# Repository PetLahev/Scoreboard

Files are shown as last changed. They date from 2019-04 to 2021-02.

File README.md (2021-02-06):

# Scoreboard 
Scoreboard created with [LED strips](https://www.amazon.com/FAVOLCANO-Waterproof-Feet%EF%BC%885M%EF%BC%89-Flexible-Lighting/dp/B012FFZP70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), ~~[Arduino Nano](https://www.amazon.com/Arduino-A000005-ARDUINO-Nano/dp/B0097AU5OU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)~~ [Arduino Uno](https://www.amazon.com/Arduino-A000066-ARDUINO-UNO-R3/dp/B008GRTSV6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) and some manual work. Handy for volleyball, table tennis, badminton, football etc.

### Why Arduino UNO
I wanted to use Nano and I designed the motherboard for using Nano but unfortunately it appeared to have one, not that serious problem for others,  but [blocker for me](https://stackoverflow.com/questions/55680065/arduino-nano-hm-10-module-not-receiving-data-on-mobile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). I was basically not able to send messages back to the HM-10 bluetooth module which is the 'main feature' of this whole scoreboard.
Thus after I built everything and was in the testing phase I found out that bluetooth communication is not working as I like. So instead of using the motherboard PCB I simply bought [UNO holder](https://store.arduino.cc/holder-type-uno) and a [terminal for UNO](https://www.amazon.com/Aideepen-Assembled-Prototype-Expansion-Bareboard/dp/B01JFQQXRS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) and made the scoreboard with it. Not that big problem as I have enough space in the box but hey ...

Scoreboard no LED strips Scoreboard powered Motherboard PCB Scorecontroller PCB Back side All PCBs

* 50 x 70 cm (19.7 x 27.55 inch) height x width
* Each segment 10 cm (3.93 inch) length so 20 cm (7.9 inch) one number! (*for points*)
* Each LED strip controlled by its own transistor
* Controlled by bluetooth module ([HM-10 Bluetooth 4.0 BLE](https://www.amazon.com/DSD-TECH-Bluetooth-iBeacon-Arduino/dp/B06WGZB2N4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))
    * Also possible to control via 433MHz module or an infra red (IR) controller
* You can use pre-defined setup for a game
* You can setup your own game
* Supports tiebreaks, sets and displaying players on service
* Score can be updated by buttons (either wired or wireless)
* As of April 2019 a free Androind application is used for controlling the scoreboard - [Serial Bluetooth Terminal](https://play.google.com/store/apps/details?id=de.kai_morich.serial_bluetooth_terminal&hl=en_US) v1.17
	* Update Feb 2021 - It was proven that the most convinient way how to control the scoreboard is an IR controller (people tend to prefer this way over others)
* Eagle schematic and boards included
* The scoreboard case designed on thinkercad.com
    * [The box](https://www.tinkercad.com/things/gNmK0jQ22qv)
    * [The display board](https://www.tinkercad.com/things/9Don7XhJEvx) - just for measuring purpose

## Setting the Serial Bluetooth Terminal
Just one device can be connected to the module at time!
Make sure you pair the bluetooth module with your smart phone, add it under the `Devices` tab and then go to the `Settings - Send` and set the `Newline` option to **none**. On the main menu tap on the connect symbol. You should get a text saying "Connected to unnamed". (*Make sure you bluetooth module is powered and the indication LED is blinking*)

## Settings
By default, the scoreboard is set as a clock (sets segment are used for seconds). There is no specific setting for turning the clock
off as this is always done by providing any setting. If you need to go back to the 'clock' mode, just turn the power off and then on.
You can setup your own game either in code - [globals.cpp](/Arduino/Scoreboard/src/globals.cpp) - or at runtime when sending the SETTING character via the Serial Bluetooth Terminal. The SETTING character is = `!` (*exclamation mark*). This behaves as a toggle switch so when send first time `!` the scoreboard will switch to 'setting mode' and will accept certain settings, when sending second time `!` it will end the 'setting mode' and will be ready for a game!

You can setup
* Number of sets (up to 9)
* Sets support - enabled/disabled
    * Number of points per a set (up to 99)
* Points difference to win a set
* Tiebreak support - enabled/disabled
    * Points in tiebreak
    * Points difference to win a tiebreak set
    * The tiebreak set
        * Set a number that represents the set in the match considered as tiebreak set. *For example, in tennis you would set number `7` here*
* Display player on service (*pre-set 4 players*) - enabled/disabled

### Application settings
The code now (*April 2019*) understands certain `key=value` pairs. Listed below but always check [settingController](/Arduino/Scoreboard/src/settingController.h) header file for the latest settings
* Enable displaying sets = `b`
* Sets per match = `s`
* Points per set = `e`
* Points difference to win a set = `d`
* Support tiebreak = `t`
* Set the tiebreak set = `q`
* Points in tiebreak = `f`
* Points difference to win a tiebreak = `w`
* Enable displaying a player on service = `r`
* Swap score = `$`
* Set player on service = `p` and then number 1 - 4
* Reset the whole game = `@`
* Turn sets segments to minute timer = `u`
    * Will automatically enable displaying sets

Examples of key-value setting

    b=true
    WIll enable sets (the LEDs will be powered)

    s=2
    A team/player needs to win 2 sets to win the match

    e=11
    A team/player needs to win 11 points to win a set
    (The points difference setting will be considered here)

    d=2
    A set will be considered as finished when the score between the teams/players
    1, reach the minimum points to win a set (e.g. 11)
    AND
    2, the difference is equal to 2
    examples: 11:9 or 13:11 or 12:10 or 21:19 etc.

    t=true
    Tiebreak is enabled

    q=2
    The tiebreak set is the second set to win. In other words this will be the third set
    For the above example the tiebreak settings will be considered when sets are 1:1

    f=9
    A team/player needs to win 9 points to win the tiebreak set

    w=2
    The tiebreak will be considered as finished when the score between the teams/players
    1, reach the minimum points to win the tiebreak set (e.g. 9)
    AND
    2, the difference is equal to 2
    examples: 9:7 or 10:8 or 11:9 etc.

    r=true
    Will enable displaying player on service (The LEDs will be powered)
    Note: There are always 4 players pre-set, not configurable as of April 2019)

    u=true
    Will turn the sets segments to display minute timer. So it will count from 0 to 9999 minutes

### Example of game settings
#### A free match (like football)
    b=false   ' disable sets
    s=0       ' no sets per match  
    e=99      ' set maximum of points
    t=false   ' tiebreak disabled
    r=false   ' disable displaying player on service

#### A beach volleyball match
    b=true    ' enable sets
    s=2       ' a team needs to win 2 sets to win a match
    e=21      ' a team needs to win 21 points to win a set
    d=2       ' the points difference between the two teams must be 2 to win a set
    t=reuw    ' tiebreak enabled
    q=2       ' the tiebreak set is the second one to win. So the sets score is 1:1
    f=15      ' a team needs to win 15 points to win the tiebreak set
    w=2       ' the points difference between the two teams must be 2 to win the tiebreak set
    r=true    ' enable displaying a player who serves

## How to use
Once your game is set and you leave the settings mode (*by sending `!` flag*) your match can start. Based on the type of your match the scoreboard will control all the aspect of the match you will just increase or decrease number of points for the **Home** or **Away** team

Send  
`h` - to give a point to **Home** team  
`a` - to give a point to **Away** team

If you make a mistake (*we all do*) you can take a point back.  
Send  
`v` - to decrease points of **Home** team  
`m` - to decrease score of **Away** team

**Please note:** Taking point back may have an affect on number of sets played, match finished, player on service etc. The code as of April 2019 cares just about simple cases and supports returning all back just for *one* point so if you made a mistake and give a point in the middle of set to a wrong team, taking the point back will work but if you made the same mistake when the team you gave won a set/match then taking the point back will NOT have any affect. It's better to start a new match by resetting the match and setting the correct score by sending few `h` or `a`.

## How to build
OK if you get here you actually may want to build your own scoreboard and I do understand that, it's much more fun!

If you just want to take the code and change it be aware that I didn't use the official Arduino IDE as I didn't find it as good as it should be. This project is made by [Visual Studio Code](https://code.visualstudio.com/) and [Platform IO](https://platformio.org/) extension both free. Once installed you should be able to build the project as it has all the settings done so you will get the right versions of used libraries and everything else. Please check [platformio.ini](/Arduino/platformio.ini) file to see if I added your Arduino board to the environment configuration. As of April 2019 I have this configuration

    [platformio]
    env_default = uno

    [env:nanoatmega328]
    platform = atmelavr
    board = nanoatmega328
    framework = arduino

    [env:uno]
    platform = atmelavr
    framework = arduino
    board = uno

The `env_default = uno` specifies for which board Platform IO builds the code, in this case is Arduino Uno. Make sure you have the right one here otherwise the code won't work.  
Let me also make you aware that I'm not C++ guy and I found it pretty hard to learn so the code is probably all messy but working.

If you also want to build the scoreboard case check the [Tinkercad page](https://www.tinkercad.com/things/gNmK0jQ22qv). I tried to make it in 1:5 scale but again it was my first experience with 3D software. The [shield](https://www.tinkercad.com/things/9Don7XhJEvx) is there only for measurement purpose. I just wanted to see to what size all the LED strips will fit and how it will look like. Based on the size I designed the [case](https://www.tinkercad.com/things/gNmK0jQ22qv).  
In terms of material use whatever will fit you. My original plan was using plastic because I didn't want to make it heavy but still not too fragile. For the first version I ended up with a 5mm wood board you can buy in hobby markets asked a joiner to cut the board into pieces and let him actually figure out how to put it all together, it cost me just ~$10 then you just need to a drill and couple screws and put it all together

To be continued

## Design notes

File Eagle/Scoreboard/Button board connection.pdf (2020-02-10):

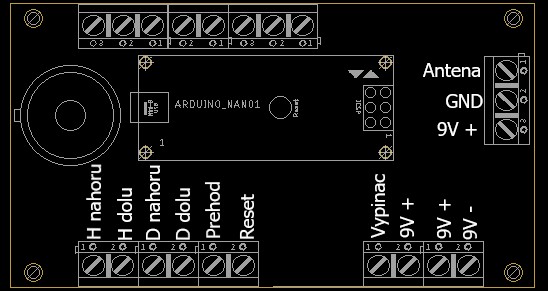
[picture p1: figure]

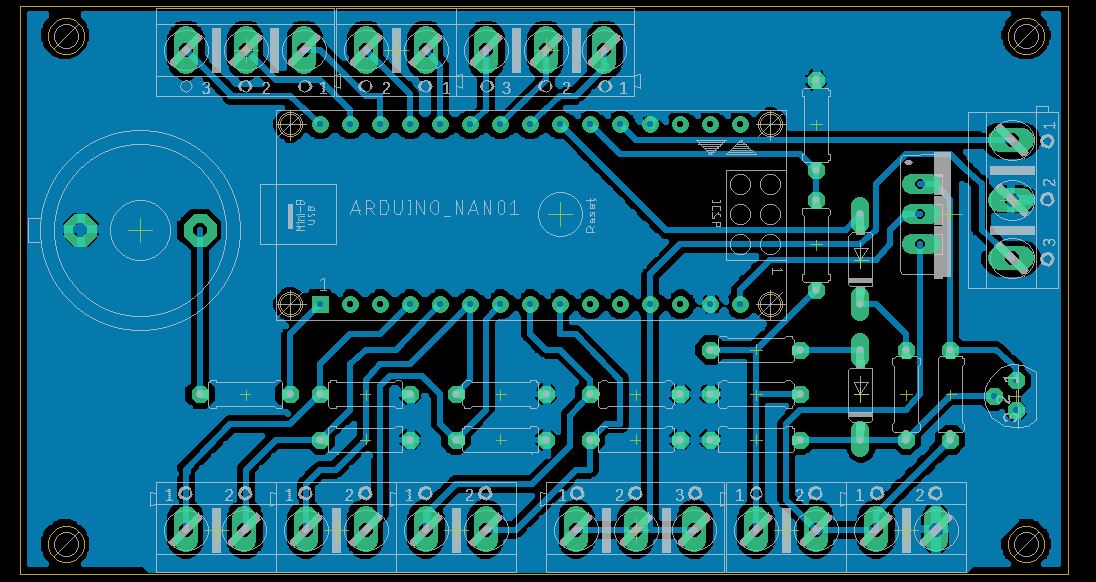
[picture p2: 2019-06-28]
images/WirelessController.png

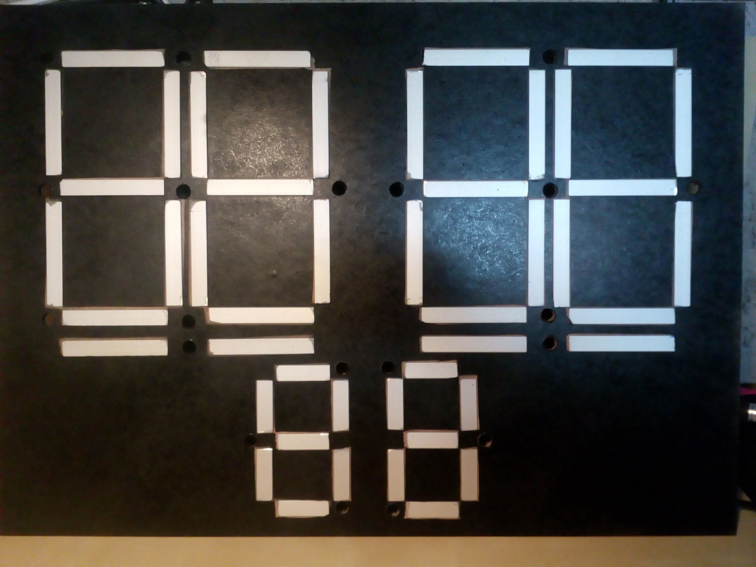
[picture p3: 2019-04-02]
images/Scoreboard no LED strips.png

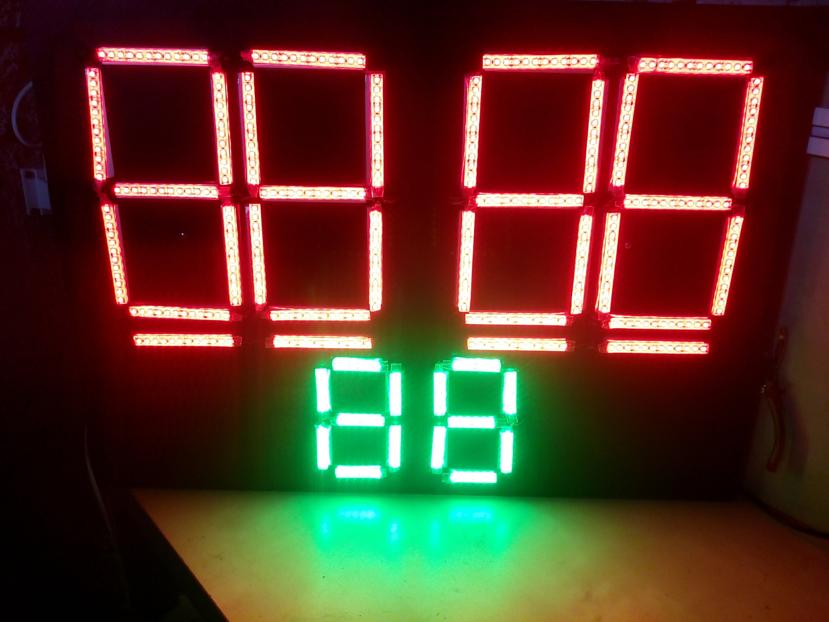
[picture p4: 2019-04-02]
images/Scoreboard powered.png

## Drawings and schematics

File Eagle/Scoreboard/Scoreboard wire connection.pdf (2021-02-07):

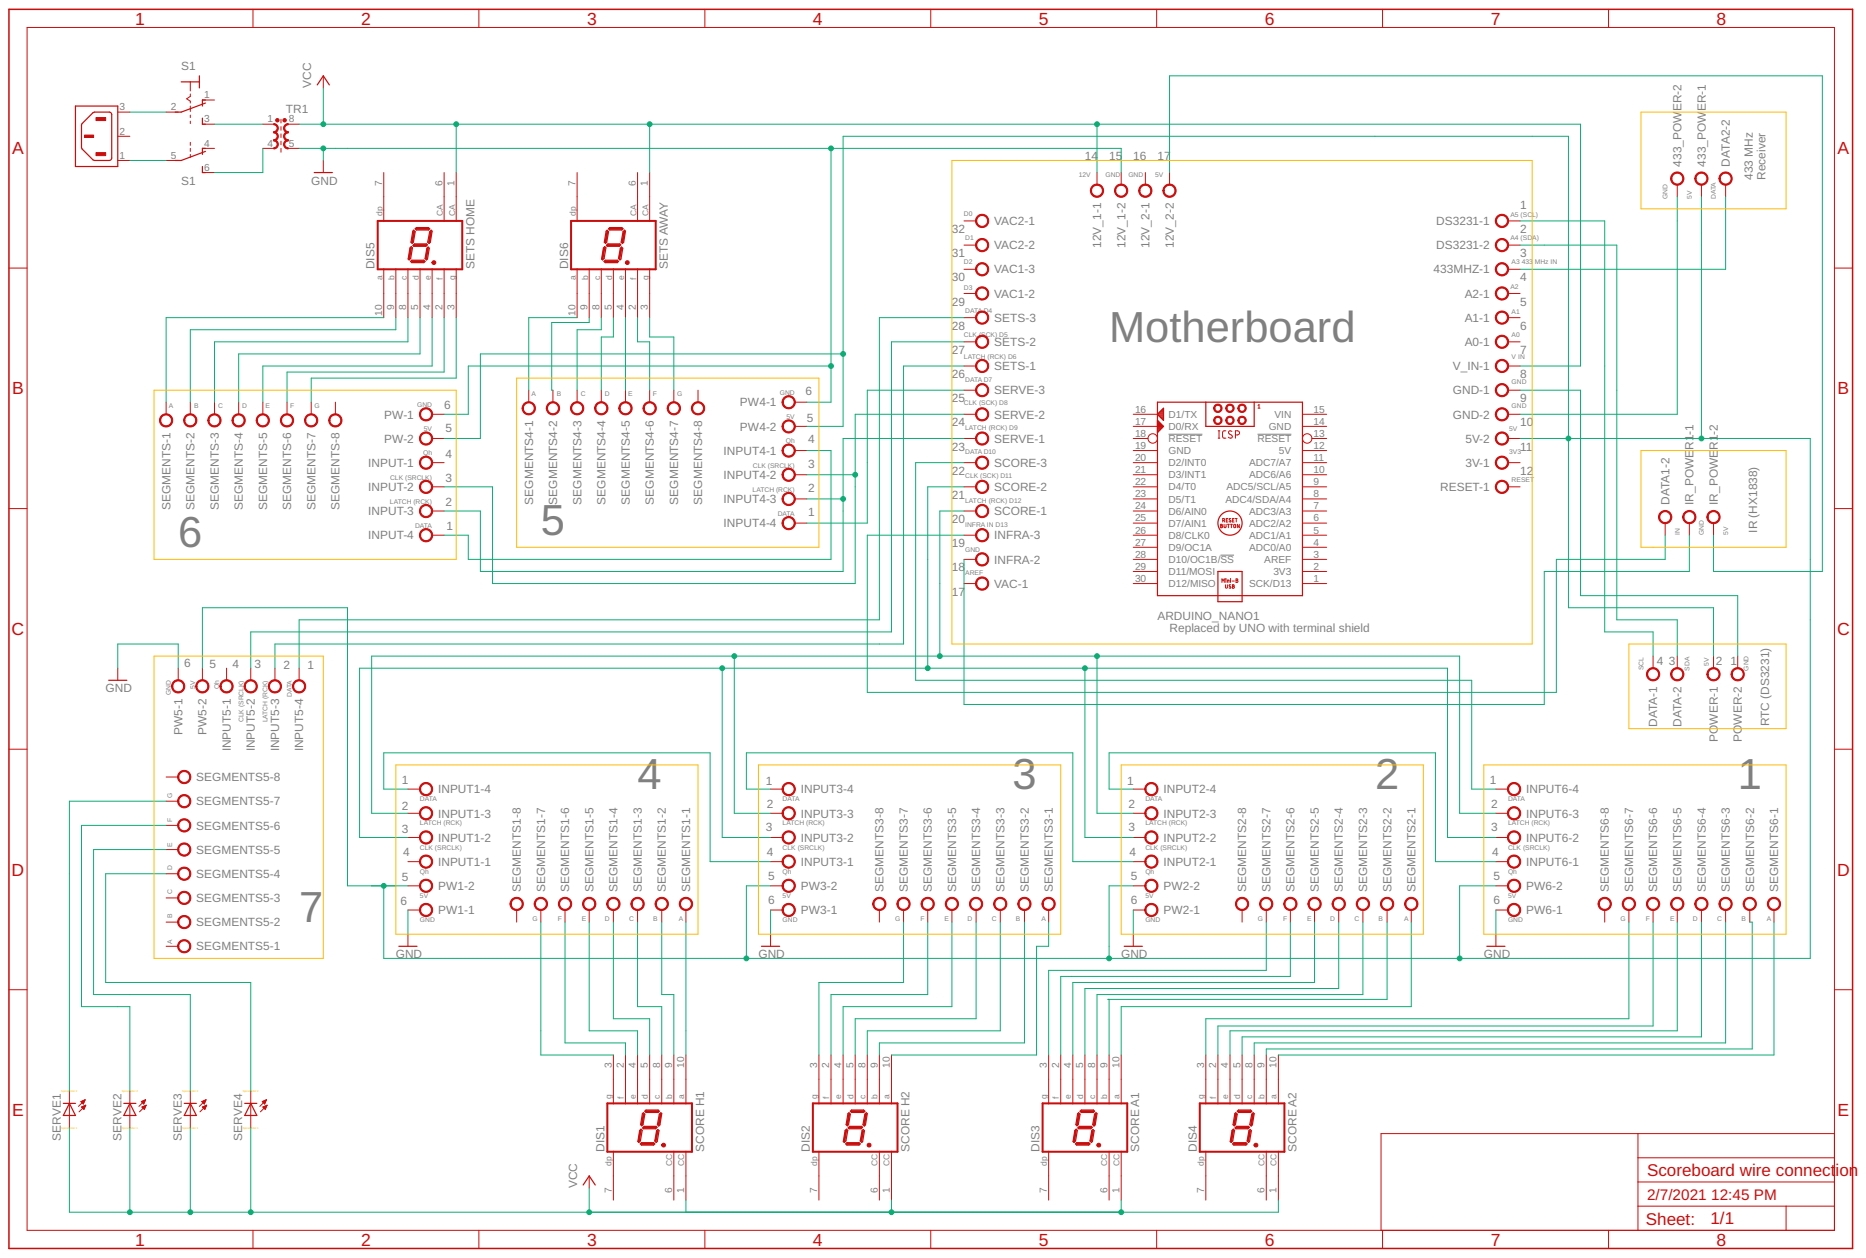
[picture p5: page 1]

LATCH (RCK) D9 CLK (SCK) D8 DATA D7
SERVE-3

LATCH (RCK) D12 CLK (SCK) D11 DATA D10
SCORE-3

LATCH (RCK) CLK (SRCLK)
INPUT4-2

INPUT-2

ARDUINO_NANO1
Replaced by UNO with terminal shield

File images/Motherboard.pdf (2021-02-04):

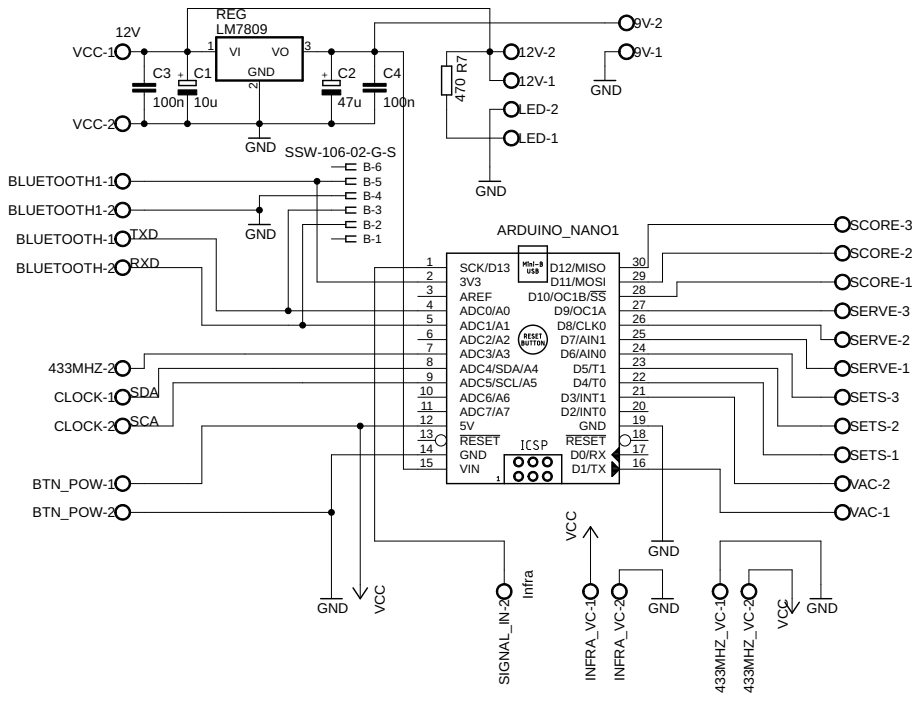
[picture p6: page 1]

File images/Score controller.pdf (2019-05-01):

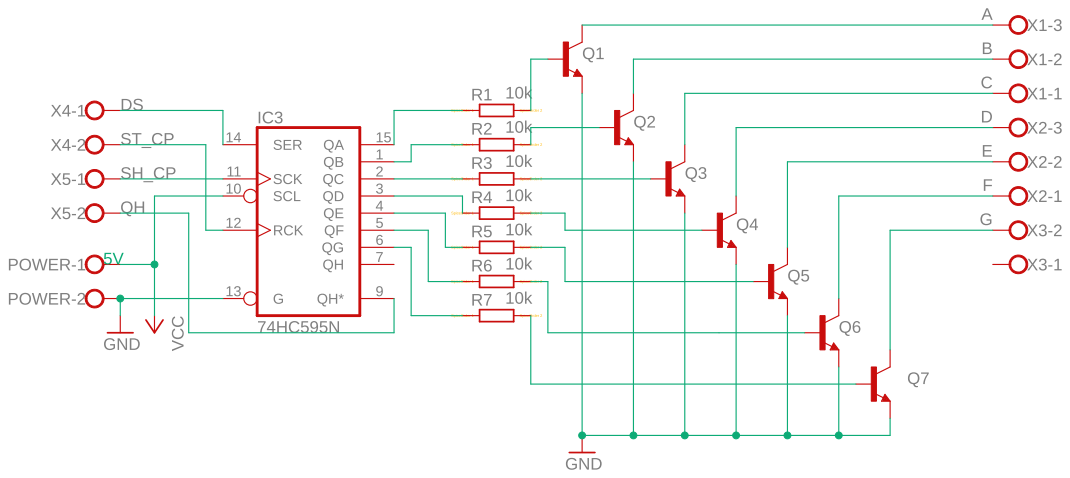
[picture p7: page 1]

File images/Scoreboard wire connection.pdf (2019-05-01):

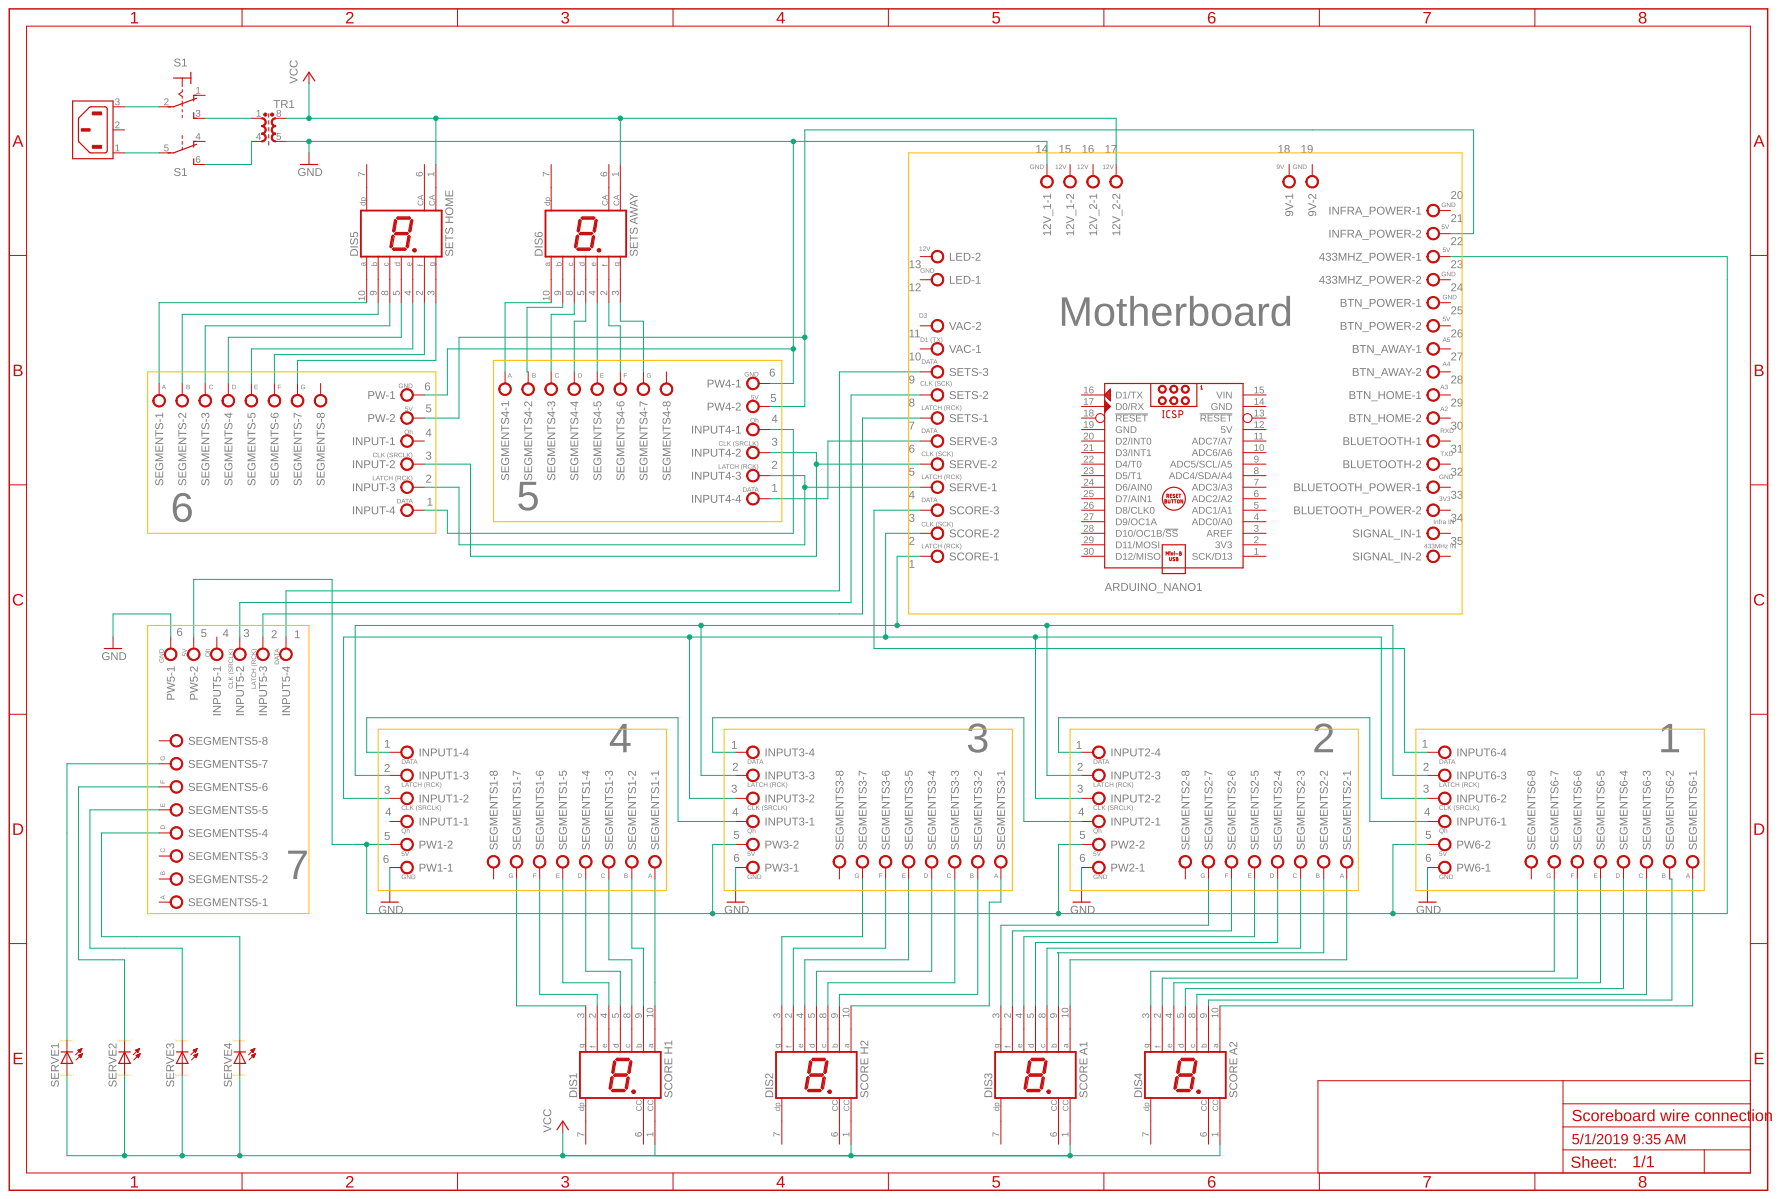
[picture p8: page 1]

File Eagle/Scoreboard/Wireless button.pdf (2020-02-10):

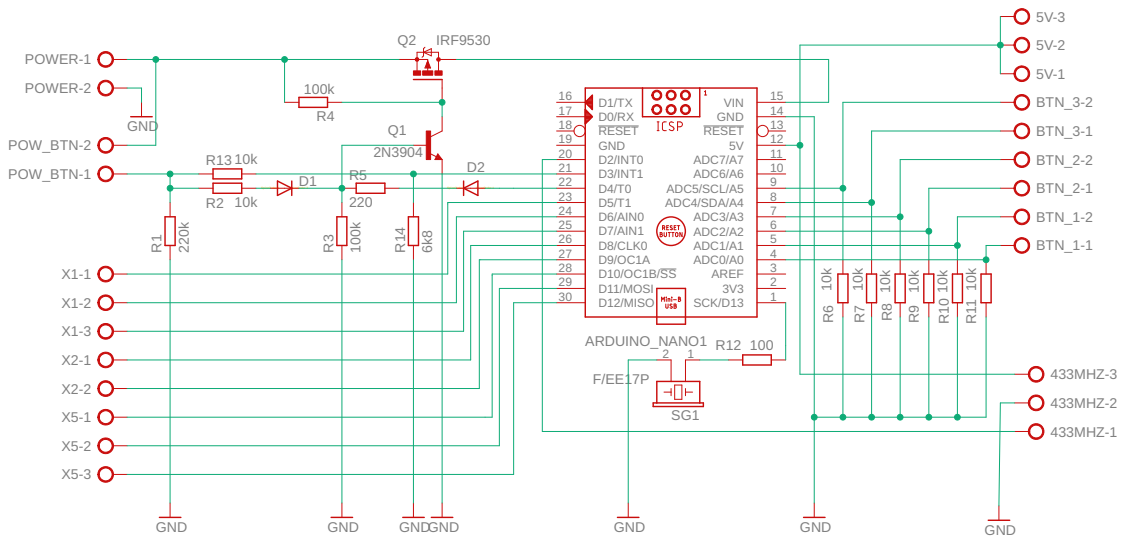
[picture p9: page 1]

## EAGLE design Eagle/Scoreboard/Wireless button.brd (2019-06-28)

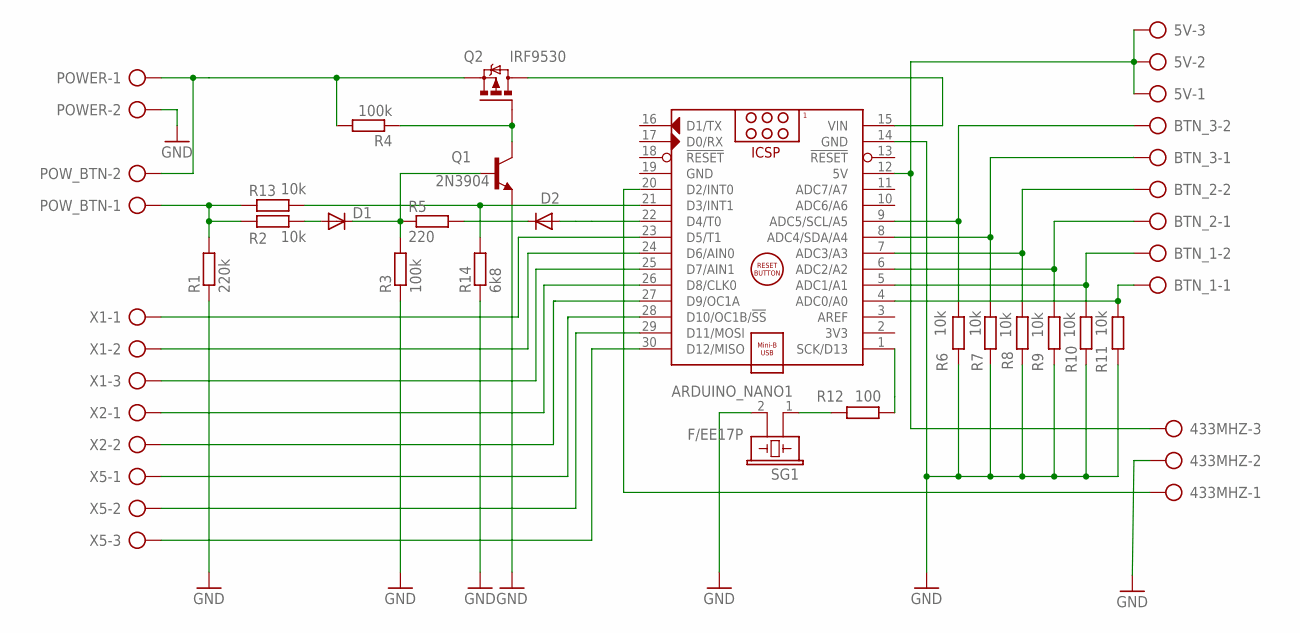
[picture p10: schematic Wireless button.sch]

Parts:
5V, 433MHZ: AK500/3
ARDUINO_NANO1: ARDUINO_NANO
BTN_1, BTN_2, BTN_3: AK500/2
D1, D2: 1N4148DO35-7; DO35-7
POWER: AK500/2
POW_BTN: AK500/2
Q1: 2N3904; TO92
Q2: IRF9530; TO220BV
R1: 220k; 0207/7
R2, R6, R7, R8, R9, R10, R11, R13: 10k; 0207/7
R3, R4: 100k; 0207/7
R5: 220; 0207/7
R12: 100; 0207/7
R14: 6k8; 0207/7
SG1: F/EE17P
X1, X5: AK500/3
X2: AK500/2

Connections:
5V: 5V.1, 5V.2, 5V.3, 433MHZ.3, ARDUINO_NANO1.12 (5V)
AWAY_DOWN: ARDUINO_NANO1.5 (ADC1/A1), BTN_1.2, R10.2
AWAY_UP: ARDUINO_NANO1.4 (ADC0/A0), BTN_1.1, R11.2
BUZZ: ARDUINO_NANO1.1 (SCK/D13), R12.2
GND: 433MHZ.2, ARDUINO_NANO1.14 (GND), ARDUINO_NANO1.19 (GND), POWER.2, Q1.3 (E), R1.1, R3.1, R6.1, R7.1, R8.1, R9.1, R10.1, R11.1, R14.1, SG1.2
HOME_DOWN: ARDUINO_NANO1.7 (ADC3/A3), BTN_2.2, R8.2
HOME_UP: ARDUINO_NANO1.6 (ADC2/A2), BTN_2.1, R9.2
unnamed: ARDUINO_NANO1.22 (D4/T0), D2.A
unnamed: Q1.1 (C), Q2.G, R4.1
unnamed: ARDUINO_NANO1.23 (D5/T1), X1.1
unnamed: D1.A, R2.2
unnamed: D1.C, Q1.2 (B), R3.2, R5.1
unnamed: D2.C, R5.2
unnamed: ARDUINO_NANO1.24 (D6/AIN0), X1.2
unnamed: ARDUINO_NANO1.25 (D7/AIN1), X1.3
unnamed: R12.1, SG1.1
unnamed: 433MHZ.1, ARDUINO_NANO1.20 (D2/INT0)
unnamed: ARDUINO_NANO1.26 (D8/CLK0), X2.1
unnamed: ARDUINO_NANO1.27 (D9/OC1A), X2.2
unnamed: ARDUINO_NANO1.28 (D10/OC1B/!SS), X5.1
unnamed: ARDUINO_NANO1.29 (D11/MOSI), X5.2
unnamed: ARDUINO_NANO1.30 (D12/MISO), X5.3
unnamed: ARDUINO_NANO1.21 (D3/INT1), R13.2, R14.2
OFF: POW_BTN.1, R1.2, R2.1, R13.1
POWER: POWER.1, POW_BTN.2, Q2.S, R4.2
RESET: ARDUINO_NANO1.9 (ADC5/SCL/A5), BTN_3.2, R6.2
SWAP: ARDUINO_NANO1.8 (ADC4/SDA/A4), BTN_3.1, R7.2
VCC: ARDUINO_NANO1.15 (VIN), Q2.D

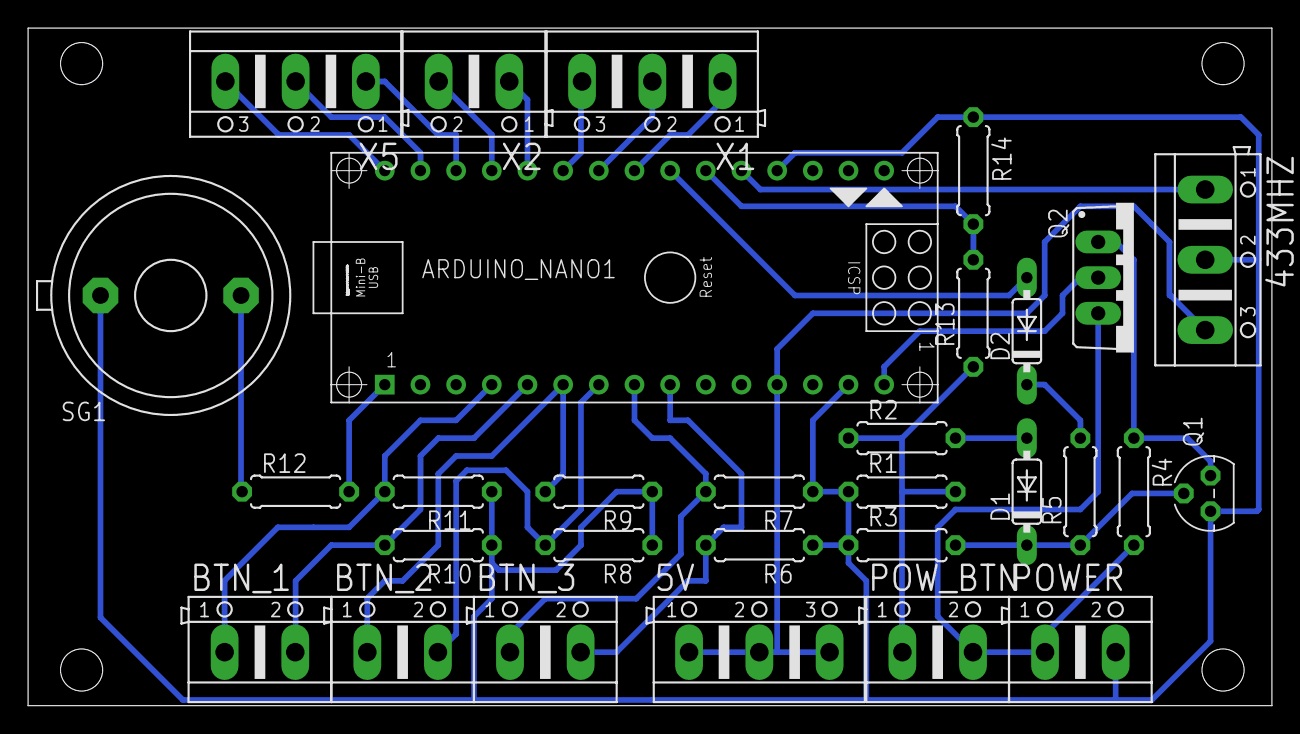
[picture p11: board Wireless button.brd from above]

Board: 2 copper layers, 88.6 x 48.2 mm, 30 parts (0 on the bottom side), 28 nets.

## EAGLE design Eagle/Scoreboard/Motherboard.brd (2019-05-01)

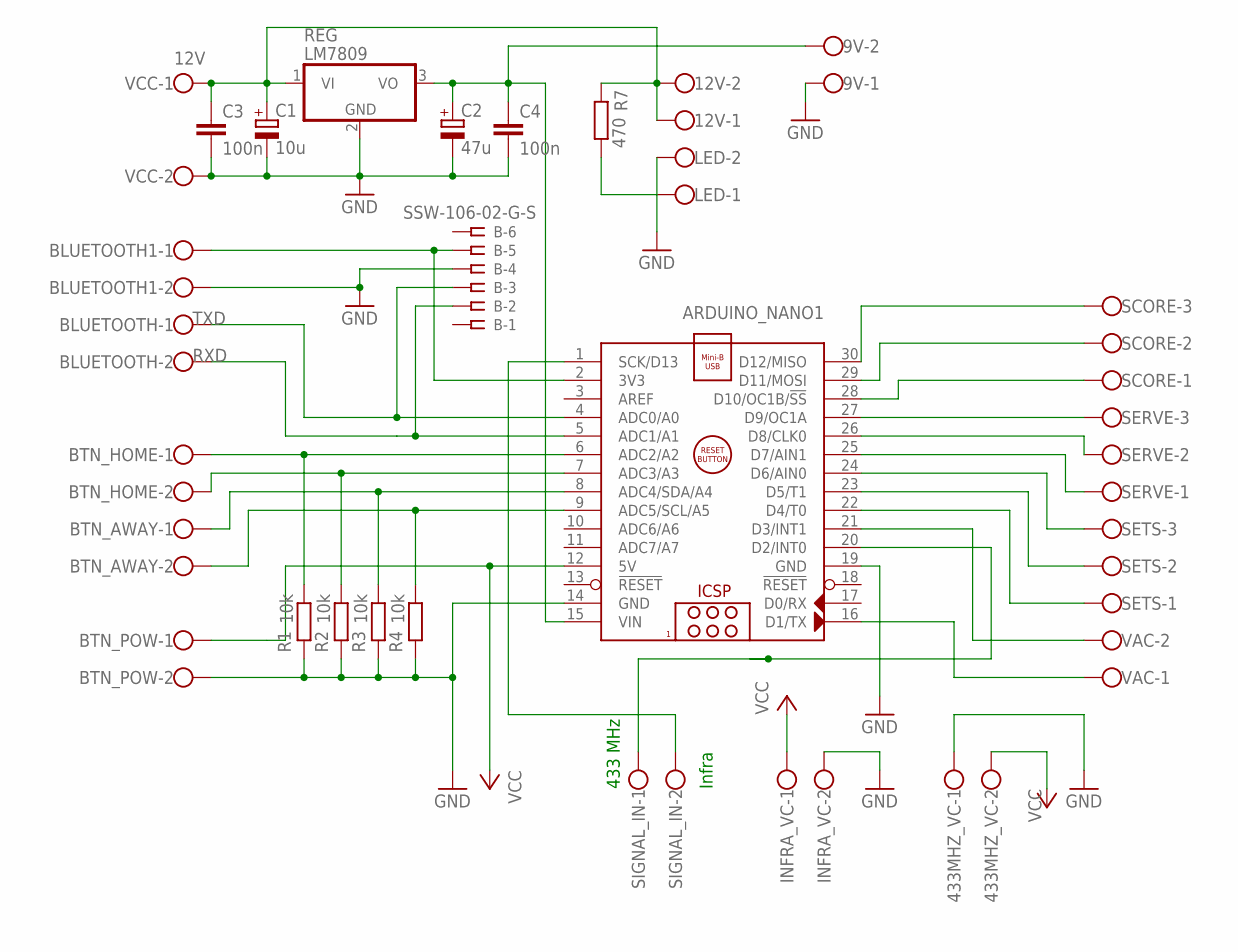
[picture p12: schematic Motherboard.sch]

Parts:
9V, 12V, 433MHZ_VC: W237-102
ARDUINO_NANO1: ARDUINO_NANO
B: SSW-106-02-G-S
BLUETOOTH, BLUETOOTH1: W237-102
BTN_AWAY: W237-102
BTN_HOME: W237-102
BTN_POW: W237-102
C1: 10u; E2-4
C2: 47u; E2-4
C3, C4: 100n; C5B2.5
INFRA_VC: W237-102
LED: W237-102
R1, R2, R3, R4: 10k; 0204/7
R7: 470; 0204/7
REG: LM7809; TO220H
SCORE: W237-103
SERVE: W237-103
SETS: W237-103
SIGNAL_IN: W237-102
VAC: W237-102
VCC: W237-102

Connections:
3V3: ARDUINO_NANO1.2 (3V3), B.5, BLUETOOTH1.1
12V: 12V.1, 12V.2, C1.+, C3.1, R7.2, REG.1 (VI), VCC.1
433MHZ: ARDUINO_NANO1.20 (D2/INT0), SIGNAL_IN.1
A2: ARDUINO_NANO1.6 (ADC2/A2), BTN_HOME.1, R1.1
A3: ARDUINO_NANO1.7 (ADC3/A3), BTN_HOME.2, R2.1
A4: ARDUINO_NANO1.8 (ADC4/SDA/A4), BTN_AWAY.1, R3.1
A5: ARDUINO_NANO1.9 (ADC5/SCL/A5), BTN_AWAY.2, R4.1
GND: 9V.1, 433MHZ_VC.1, ARDUINO_NANO1.14 (GND), ARDUINO_NANO1.19 (GND), B.4, BLUETOOTH1.2, BTN_POW.2, C1.-, C2.-, C3.2, C4.2, INFRA_VC.2, LED.2, R1.2, R2.2, R3.2, R4.2, REG.2 (GND), VCC.2
INFRA: ARDUINO_NANO1.1 (SCK/D13), SIGNAL_IN.2
unnamed: ARDUINO_NANO1.21 (D3/INT1), VAC.2
unnamed: ARDUINO_NANO1.16 (D1/TX), VAC.1
unnamed: LED.1, R7.1
RXD: ARDUINO_NANO1.5 (ADC1/A1), B.2, BLUETOOTH.2
SCORE_1: ARDUINO_NANO1.28 (D10/OC1B/!SS), SCORE.1
SCORE_2: ARDUINO_NANO1.29 (D11/MOSI), SCORE.2
SCORE_3: ARDUINO_NANO1.30 (D12/MISO), SCORE.3
SERVE_1: ARDUINO_NANO1.25 (D7/AIN1), SERVE.1
SERVE_2: ARDUINO_NANO1.26 (D8/CLK0), SERVE.2
SERVE_3: ARDUINO_NANO1.27 (D9/OC1A), SERVE.3
SETS_1: ARDUINO_NANO1.22 (D4/T0), SETS.1
SETS_2: ARDUINO_NANO1.23 (D5/T1), SETS.2
SETS_3: ARDUINO_NANO1.24 (D6/AIN0), SETS.3
TXD: ARDUINO_NANO1.4 (ADC0/A0), B.3, BLUETOOTH.1
VCC: 433MHZ_VC.2, ARDUINO_NANO1.12 (5V), BTN_POW.1, INFRA_VC.1
VIN_9V: 9V.2, ARDUINO_NANO1.15 (VIN), C2.+, C4.1, REG.3 (VO)

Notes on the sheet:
RXD
TXD
433 MHz
Infra

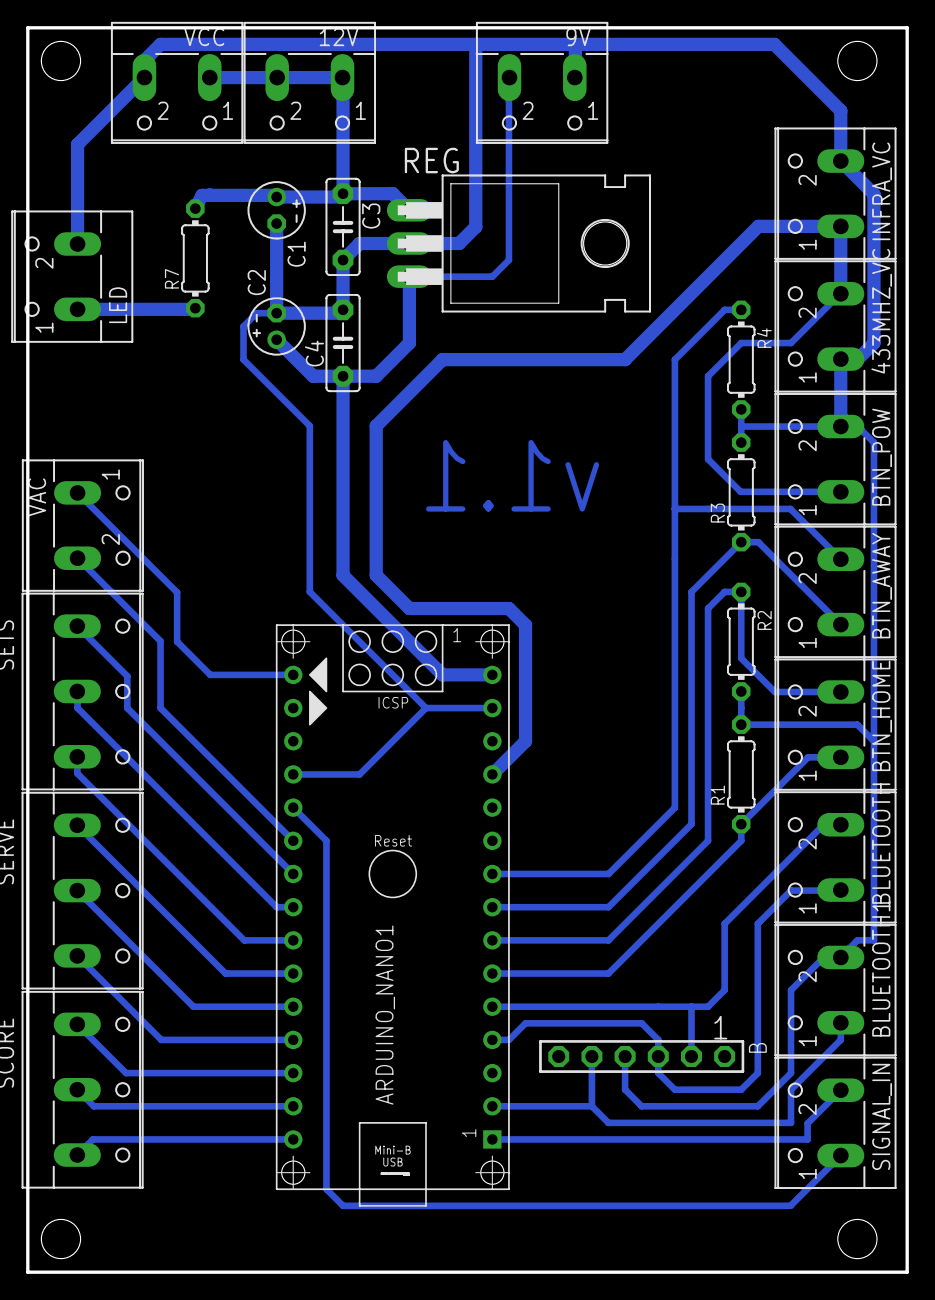
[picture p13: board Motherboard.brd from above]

Board: 2 copper layers, 67.3 x 95.2 mm, 28 parts (0 on the bottom side), 25 nets.

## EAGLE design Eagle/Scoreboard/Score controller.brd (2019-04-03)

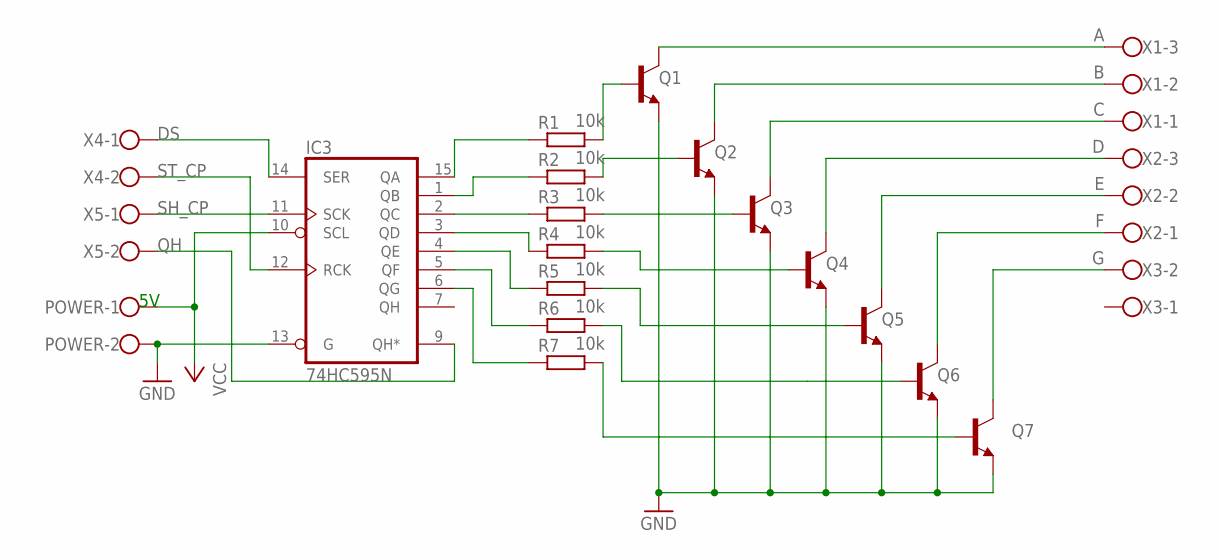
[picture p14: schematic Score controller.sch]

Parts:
IC3: 74HC595N; DIL16
POWER: W237-102
Q1, Q2, Q3, Q4, Q5, Q6, Q7: BC338-40; TO92-EBC
R1, R2, R3, R4, R5, R6, R7: 10k; 0204/7
X1, X2: W237-103
X3, X4, X5: W237-102

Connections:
A: Q1.C, X1.3
B: Q2.C, X1.2
C: Q3.C, X1.1
D: Q4.C, X2.3
DS: IC3.14 (SER), X4.1
E: Q5.C, X2.2
F: Q6.C, X2.1
G: Q7.C, X3.2
GND: IC3.8 (GND), IC3.13 (G), POWER.2, Q1.E, Q2.E, Q3.E, Q4.E, Q5.E, Q6.E, Q7.E
unnamed: IC3.1 (QB), R2.1
unnamed: Q1.B, R1.2
unnamed: IC3.2 (QC), R3.1
unnamed: IC3.15 (QA), R1.1
unnamed: Q2.B, R2.2
unnamed: IC3.3 (QD), R4.1
unnamed: IC3.4 (QE), R5.1
unnamed: IC3.5 (QF), R6.1
unnamed: IC3.6 (QG), R7.1
unnamed: Q3.B, R3.2
unnamed: Q4.B, R4.2
unnamed: Q5.B, R5.2
unnamed: Q6.B, R6.2
unnamed: Q7.B, R7.2
QH: IC3.9 (QH*), X5.2
SH_CP: IC3.11 (SCK), X5.1
ST_CP: IC3.12 (RCK), X4.2
VCC: IC3.10 (SCL), IC3.16 (VCC), POWER.1

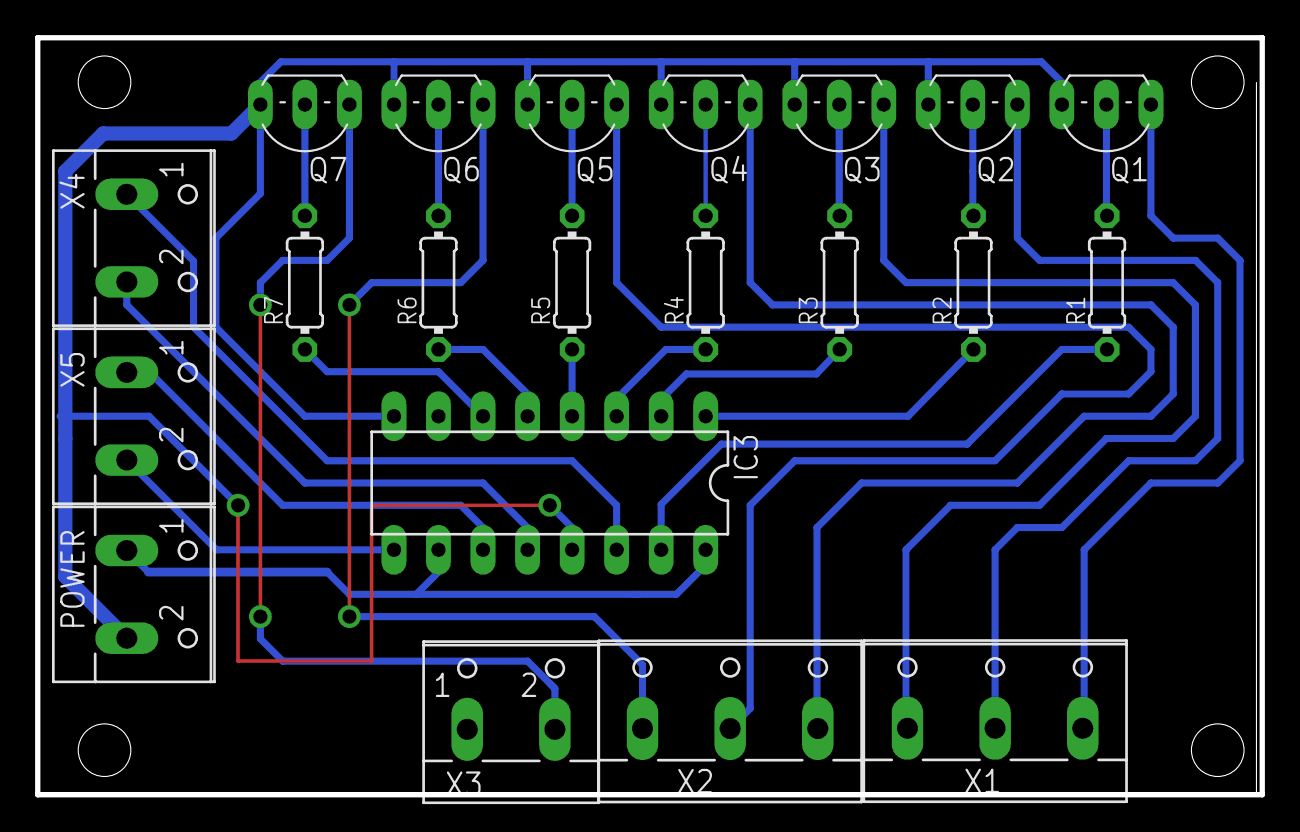
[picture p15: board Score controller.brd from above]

Board: 2 copper layers, 69.8 x 43.2 mm, 21 parts (0 on the bottom side), 27 nets.

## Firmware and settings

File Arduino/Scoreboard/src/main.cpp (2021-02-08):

/*
    Description here
*/

#include <Arduino.h>
#include "constants.h"
#include "globals.h"
#include "NeoSWSerial.h"
#include "displayController.h"
#include "scoreController.h"
#include "VirtualWire.h"
#include "settingController.h"
#include "IRremote.h"
#include "RTClib.h"

unsigned long startTime = 0;
unsigned long minutes = 0;
uint8_t lastDisplayedMinute = 1;
uint8_t lastDisplayedSecond = 0;
bool inSettingsMode;
bool inPlayerSettings;
scoreController score;
displayController display;
settingsController settings;

/**
*  Initializes IR remoteobject with pins
**/
IRrecv irRemote(IR_PIN);
decode_results irMessage;

/**
 * Initializes real time clock DS3231 variable
**/
RTC_DS3231 rtc;

const int KEY_VALUE_PAIR_LEN = 30;
const int unsigned long minuteInMillis = 60000;

void resetProcedures();
void decodeIRSignal(unsigned long irCode);

void setup()
{

    Serial.println(F("Initializing…"));

    // Initializing transmitter/receiver communication
    Serial.begin(9600);
    vw_set_ptt_inverted(true);
    vw_setup(1000);
    vw_set_rx_pin(RECEIVER_PIN);
    vw_rx_start();
    Serial.println(F("VirtualWire initialized"));

    // Initialize IR Remote communication
    irRemote.enableIRIn();
    Serial.println(F("IR Remote communication initialized"));

    // Initializing bluetooth communication
    bluetooth.begin(9600);
    bluetooth.println(F("Bluetooth turned on"));
    Serial.println(F("Bluetooth initialized"));

    if (!rtc.begin())
    {
        Serial.println("Couldn't find RTC, switching to 'minute' mode");
        Serial.flush();
        // switching to 'minute' mode
        setsAsMinute = true;
        setsAsClock = false;
    }

    if (rtc.lostPower())
    {
        // When time needs to be set on a new device, or after a power loss, the
        // following line sets the RTC to the date & time this sketch was compiled
        rtc.adjust(DateTime(F(__DATE__), F(__TIME__)));
    }

    // When time needs to be re-set on a previously configured device, the
    // following line sets the RTC to the date & time this sketch was compiled
    // rtc.adjust(DateTime(F(__DATE__), F(__TIME__)));
    // This line sets the RTC with an explicit date & time, for example to set
    // January 21, 2014 at 3am you would call:
    // rtc.adjust(DateTime(2014, 1, 21, 3, 0, 0));

    pinMode(SCORE_LATCH_PIN, OUTPUT);
    pinMode(SCORE_CLK_PIN, OUTPUT);
    pinMode(SCORE_DATA_PIN, OUTPUT);

    pinMode(SETS_LATCH_PIN, OUTPUT);
    pinMode(SETS_CLK_PIN, OUTPUT);
    pinMode(SETS_DATA_PIN, OUTPUT);

    pinMode(PLAYER_LATCH_PIN, OUTPUT);
    pinMode(PLAYER_CLK_PIN, OUTPUT);
    pinMode(PLAYER_DATA_PIN, OUTPUT);

    inPlayerSettings = false;
    inSettingsMode = false;
    display.greetings();
    score.reset();
}

void loop()
{

    uint8_t data = 0;
    if (bluetooth.available() > 0)
    {
        // read the data from bluetooth
        if (!inSettingsMode)
            data = bluetooth.read();
        if (data == SETTINGS)
        {
            // if the first received char equals the flag for settings mode
            // it will toggle betwen the ON/OFF state
            inSettingsMode = !inSettingsMode;
            if (inSettingsMode)
            {
                bluetooth.println(F("In settings mode"));
                Serial.println(F("In settings mode"));
                // prints out current setting
                settings.read();
                Serial.println(data);
                return;
            }
        }

        if (inSettingsMode)
        {
            char keyValuePair[KEY_VALUE_PAIR_LEN];
            bool dataAvailable;
            // if required, change the settings here
            // when user wants to end the settings mode
            // the SETTINGS constant needs to be sent
            if (bluetooth.available() > 0)
            {
                data = bluetooth.read();
                if (data == SETTINGS)
                {
                    inSettingsMode = false;
                    startTime = millis();
                    bluetooth.println(F("Ended settings mode"));
                    Serial.println(F("Ended settings mode"));
                    return;
                }
                else
                {
                    keyValuePair[0] = data;
                    dataAvailable = true;
                }
            }

            for (size_t i = 1; i < KEY_VALUE_PAIR_LEN; i++) // apparently not that easy to calculate size of array in C++
            {
                // gets the settings data
                if (bluetooth.available() > 0)
                {
                    keyValuePair[i] = bluetooth.read();
                    dataAvailable = true;
                    delay(10);
                }
                else
                {
                    // write char for end of string
                    keyValuePair[i] = '\0';
                }
            }

            // if any data available for settings, calls the settings controller
            if (dataAvailable)
            {
                // always turn clock off
                // the clock is default setting when the scoreboard is powered up
                setsAsClock = false;
                settings.set(keyValuePair);
            }
        }
        else
        {
            // set the variable for receiver message, max length is 78
            Serial.println(data);

            if (data == RESET_ALL)
            {
                resetProcedures();
                return;
            }

            if (data != SWAP_DISPLAY)
            {

                if (data == SET_SERVER || inPlayerSettings)
                {
                    Serial.println(F("in player setting IF"));
                    if (!inPlayerSettings)
                    {
                        // let's wait for a number that represents the player who should serve
                        inPlayerSettings = !inPlayerSettings;
                        Serial.println(F("Turning ON setting player mode"));
                    }
                    else
                    {
                        score.setPlayerServe(data);
                        // get out from the player settings mode
                        inPlayerSettings = !inPlayerSettings;
                        Serial.println(F("Turning OFF setting player mode"));
                    }
                }
                else
                {
                    score.updateScore(data);
                }
            }
            else
            {
                score.swapScore();
            }
        }
        return; // if bluethoot data processed do not check other channels
    }

    // This is for 433MHz receiver
    // set the variable for receiver message, max length is 78
    uint8_t message[VW_MAX_MESSAGE_LEN];
    uint8_t messageLen = 1;
    if (vw_get_message(message, &messageLen))
    {
        // little hack here
        // we do not expect to get any more chars than exact one (not planning use it for settings)
        // given the hardware implementation (just 4 buttons for updating score)
        // I'd be probably able to construct a string but I've heard it consumes lots of memory
        data = message[0];

        Serial.print(F("433Mhz channel - message: "));
        Serial.println((char)data);

        if (data == RESET_ALL)
        {
            resetProcedures();
            return;
        }

        if (data == SWAP_DISPLAY)
        {
            score.swapScore();
            return;
        }
        score.updateScore(message[0]);
    }

    // This is for IR Remote communication
    if (irRemote.decode(&irMessage))
    {
        decodeIRSignal(irMessage.value);
        delay(500);
        // continue to process IR commands
        irRemote.resume();
    }

    if (setsAsMinute && !setsAsClock && !inSettingsMode)
    {
        // updates the minute on the board
        // if the minute has changed from last captured time
        // the 'startTime' and 'lastDisplayedMinute' is reset when
        // - scoreboard is reset by user
        // - settings mode ends
        if (millis() - startTime >= minuteInMillis)
        {
            startTime = millis();
            display.updateTime(lastDisplayedMinute);
            lastDisplayedMinute += 1;
        }
    }

    if (setsAsClock && !inSettingsMode)
    {
        DateTime now = rtc.now();
        if (now.second() != lastDisplayedSecond)
        {
            lastDisplayedSecond = now.second();
            display.updateTime(now.hour(), now.minute(), now.second());
        }
    }

    delay(50);
}

void resetProcedures()
{
    score.reset();
    startTime = millis();
    display.updateTime(0);
    lastDisplayedMinute = 1;
    lastDisplayedSecond = 0;
}

void decodeIRSignal(unsigned long irCode)
{
    switch (irCode)
        {
        case 0xFFA25D: // key CH- (Home team down)
        case 0x69CE021D: // Volume down (Home team down)
            score.updateScore(TEAM1_DOWN);
            break;
        case 0xFFE21D: // key CH+ (Home team up)
        case 0x76EC43A2: // volume up (Home team up)
            score.updateScore(TEAM1_UP);
            break;
        case 0xFF22DD: // key PREV (Away team down)
        case 0xC5B4F5CF: // Prog down (Away team down)
            score.updateScore(TEAM2_DOWN);
            break;
        case 0xFFC23D: // key PLAY (Away team up)
        case 0x5105CA72: // Prog up (Away team up)
            score.updateScore(TEAM2_UP);
            break;
        case 0xFF9867: // 100
        case 0x15E972C1: // info
            score.swapScore();
            break;
        case 0xFFB04F: // 200
        case 0xA4A34BB: // Recall
            resetProcedures();
            break;
        case 0xCEF2A271: // red button
            setsAsMinute = true;
            setsAsClock = false;
            resetProcedures();
            display.blinkScore();
            break;
        case 0xD071A5F0: // green button
            resetProcedures();
            settings.setPreDefinedGame(settingsController::Setting::BeachVolleyball);
            display.blinkScore();
            break;
        case 0xEF7FB1A7: // yellow button
            resetProcedures();
            settings.setPreDefinedGame(settingsController::Setting::Volleyball);
            display.blinkScore();
            break;
        case 0xF18403D5: // blue button
            resetProcedures();
            settings.setPreDefinedGame(settingsController::Setting::Badminton);
            display.blinkScore();
            break;
        case 0xDC10E3F6: // time button
            setsAsMinute = false;
            setsAsClock = true;
            resetProcedures();
            break;
        default:
            Serial.print("Unknow IR Remote button: ");
            Serial.println(irMessage.value, HEX);
        }
}

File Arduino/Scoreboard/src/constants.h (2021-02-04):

/*
  Contains all shared constatnts
  Note: Objects that need to be initialized are in globals.cpp
*/

#ifndef Constants_h
#define Constants_h

#include <stdint.h>
#include "NeoSWSerial.h"

/*
  Defines pins for the bluetooth communication
*/
const uint8_t BLUE_RX = A1;
const uint8_t BLUE_TX = A0;

/*
  Defines pins for wireless communication (433Mhz)
*/
const uint8_t RECEIVER_PIN = A3;

/*
  Defines pin for IR remote
*/
const uint8_t IR_PIN = 13;

/*
  All segments off
*/
const uint8_t SEGMENT_OFF = 0b00000000;

/*
  Defines pins for score controlles
*/
const uint8_t SCORE_LATCH_PIN = 12;  // RCLK (RCK) pin 12 74HC595
const uint8_t SCORE_CLK_PIN = 11;    // SRCLK (SCK) pin 11 74HC595
const uint8_t SCORE_DATA_PIN = 10;   // SER  pin 14 74HC595

/*
  Defines pins for sets controlles 
*/
const uint8_t SETS_LATCH_PIN = 6;     // RCLK (RCK) pin 12 74HC595
const uint8_t SETS_CLK_PIN = 5;       // SRCLK (SCK) pin 11 74HC595
const uint8_t SETS_DATA_PIN = 4;      // SER  pin 14 74HC595

/*
  Defines pins for players who should serve
*/
const uint8_t PLAYER_LATCH_PIN = 9;   // RCLK (RCK) pin 12 74HC595
const uint8_t PLAYER_CLK_PIN = 8;     // SRCLK (SCK) pin 11 74HC595
const uint8_t PLAYER_DATA_PIN = 7;    // SER  pin 14 74HC595


const char TEAM1_UP = 'h';
const char TEAM1_DOWN = 'v';
const char TEAM2_UP = 'a';
const char TEAM2_DOWN = 'm';
const char SET_SERVER = 'p';
const char SWAP_DISPLAY = '$';
const char RESET_ALL = '@';
const char SETTINGS = '!';
const uint8_t MAX_SCORE = 99;
const uint8_t TEAM1 = 1;
const uint8_t TEAM2 = 2;
#endif

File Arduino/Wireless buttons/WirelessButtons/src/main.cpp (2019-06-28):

/*
  Uses a few buttons and 433 MHz transciever to communicate
  with the scoreboard. We can controll points, set player
  reset whole match and use pre-defined game settings
*/

#include <Arduino.h>
#include <EasyButton.h>
#include <VirtualWire.h> 

#define BTN_HOME_UP A2
#define BTN_HOME_DOWN A3
#define BTN_AWAY_UP A0
#define BTN_AWAY_DOWN A1
#define BTN_SWAP A4
#define BTN_RESET_ALL A5
#define BTN_POWER_OFF 3
#define COMMUNICATION_PIN 2
#define BUZZER_PIN 13
#define POWER_LATCH_PIN 4


unsigned long lastActionMillis;
const unsigned long inactivityPeriod = 600000; //the value is a number of milliseconds here 10 minutes

bool homePlayer = true;
bool awayPlayer = true;

// Instance of the button.
EasyButton btnHomeUp(BTN_HOME_UP);
EasyButton btnHomeDown(BTN_HOME_DOWN);
EasyButton btnAwayUp(BTN_AWAY_UP);  
EasyButton btnAwayDown(BTN_AWAY_DOWN);
EasyButton btnSwapScore(BTN_SWAP);
EasyButton btnReset(BTN_RESET_ALL);
EasyButton btnPowerOff(BTN_POWER_OFF);

void sendMessage(char* message) {
  // to reset the last action counter for self shutdown
  lastActionMillis = millis();
  Serial.println("Sending message");
  digitalWrite(13, HIGH);  
  vw_send((uint8_t *)message, strlen(message));  
  vw_wait_tx();
  tone(BUZZER_PIN, 800);
  delay(1000);
  digitalWrite(13, LOW);
  noTone(BUZZER_PIN);
}

// Callback functions 
void onHomeUpPressed() {	
  Serial.println("Home up pressed");
  sendMessage("h");
}

void onHomeDownPressed() {	
  Serial.println("Home down pressed");
  sendMessage("v");
}

void onAwayUpPressed() {	
  Serial.println("Away up pressed");
  sendMessage("a");
}

void onAwayDownPressed() {	
  Serial.println("Away down pressed");
  sendMessage("m");
}

void onSwapScorePressed() {	
  Serial.println("Swap score pressed");
  sendMessage("$");  
}

void onResetPressed() {	
  if (millis() < 3000) {
    Serial.println("Reset was cancelled due to initialization code");
    return;
  }
  Serial.println("Reset pressed");
  sendMessage("@");
}

void onPowerPressed() {
  Serial.println("Power button pressed");
  tone(BUZZER_PIN, 1300);
  delay(400);
  noTone(BUZZER_PIN);
  delay(400);
  tone(BUZZER_PIN, 1300);
  delay(400);
  noTone(BUZZER_PIN);
  delay(400);
  tone(BUZZER_PIN, 1500);
  delay(600);
  noTone(BUZZER_PIN);
  // this will shut down the power
  digitalWrite(POWER_LATCH_PIN, LOW);
}

void onPowerOffPressed() {
  Serial.println("Power OFF button pressed");
  tone(BUZZER_PIN, 3500);
  delay(600);
  noTone(BUZZER_PIN);
}

void setup() {  
  
  pinMode(POWER_LATCH_PIN, OUTPUT);
  pinMode(BTN_POWER_OFF, INPUT);
  
  // Keeps the circuit on
  digitalWrite(POWER_LATCH_PIN, HIGH);

  Serial.begin(9600);
  Serial.println("Initializing");

  // set the type of communication
  vw_set_ptt_inverted(true);
  // the speed in bits per sec
  vw_setup(1000);  
  vw_set_tx_pin(COMMUNICATION_PIN);

  Serial.println("Communication set up");

  btnHomeUp.begin();
  btnHomeDown.begin();
  btnAwayUp.begin();
  btnAwayDown.begin();
  btnSwapScore.begin();  
  btnReset.begin();
  btnPowerOff.begin();

  btnHomeUp.onPressed(onHomeUpPressed);
  btnHomeDown.onPressed(onHomeDownPressed);
  btnAwayUp.onPressed(onAwayUpPressed);
  btnAwayDown.onPressed(onAwayDownPressed);
  btnSwapScore.onPressed(onSwapScorePressed);  
  btnReset.onPressedFor(2000, onResetPressed);  
  btnPowerOff.onPressed(onPowerPressed);

  pinMode(13, OUTPUT);  
  tone(BUZZER_PIN, 1300);
  delay(600);
  noTone(BUZZER_PIN);

  Serial.println("Buttons initialized");
}

void loop() {
  btnHomeUp.read();
  btnHomeDown.read();
  btnAwayUp.read();
  btnAwayDown.read();  
  btnSwapScore.read();
  btnReset.read();  
  btnPowerOff.read();
  delay(50);

  // cut off the power if there was no activity for some time
  if ((millis() - lastActionMillis) >= inactivityPeriod) {
     onPowerPressed();
  }  

}

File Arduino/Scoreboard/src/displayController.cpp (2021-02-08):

/*
    Responsible for managing the display itself
*/

#include "globals.h"
#include "constants.h"
#include "displayController.h"

displayController::displayController()
{
    Serial.println("Score controller created");
}

/**
 *  Displays score include sets and servers if enabled
 *  @params score1 - score for the team 1
 *          score2 - score for the team 2
 *          set1   - number of sets won by first team (if enabled)
 *          set2   - number of sets won by second team (if enabled)
 *          player - player on service, supports value from 1- 4 (if enabled)
 **/
void displayController::score(uint8_t score1, uint8_t score2, uint8_t set1, uint8_t set2, uint8_t player)
{
    showScore(score1, score2);
    showWhoServe(player);
    if (!setsAsMinute)
        showSets(set1, set2); // do not update the sets when it's beeing used for minutes
}

void displayController::showScore(uint8_t score1, uint8_t score2, bool displayLeadingZero = false)
{

    // We are going from left (team1) to right (team2)
    // so the first index of the array will be the very left segment on the scoreboard
    // the the last index will be the very right segment on the scoreboard
    //   __   __    __   __
    //  |__| |__|  |__| |__|
    //  |__| |__|  |__| |__|
    //   [0] [1]   [2]  [3]
    //
    // All segments off by default
    uint8_t digits[4] = {digitOne[10], digitOne[10], digitOne[10], digitOne[10]};

    uint8_t remind = 0;
    uint8_t digit = 0;
    if (score1 > 9)
    {
        remind = score1 / 10;
        digit = score1 % 10;
        digits[0] = digitOne[remind];
        digits[1] = digitOne[digit];
    }
    else
    {
        // the second segment from left will be set to the represent number from 0-9
        if (displayLeadingZero)
        {
            digits[0] = digitOne[0];
        }
        digits[1] = digitOne[score1];
    }

    if (score2 > 9)
    {
        remind = score2 / 10;
        digit = score2 % 10;
        digits[2] = digitOne[remind];
        digits[3] = digitOne[digit];
    }
    else
    {
        // the from segment from left will be set to the represent number from 0-9
        if (displayLeadingZero)
        {
            digits[2] = digitOne[0];
        }
        digits[3] = digitOne[score2];
    }

    data.firstBigSegment = digits[0];
    data.secondBigSegment = digits[1];
    data.thirdBigSegment = digits[2];
    data.fourthdBigSegment = digits[3];

    // Write the bytes to the score output
    digitalWrite(SCORE_LATCH_PIN, LOW);
    for (uint8_t i = 0; i < 4; i++)
    {
        shiftOut(SCORE_DATA_PIN, SCORE_CLK_PIN, LSBFIRST, digits[i]);
    }
    digitalWrite(SCORE_LATCH_PIN, HIGH);
}

/**
 * Blinks the whole display whatever was supplied as last information
 **/
void displayController::blink()
{

    Serial.println(F("Display blink start"));
    // It assumes the information is already displayed
    // turn everything off and then display again for 3 times
    for (uint8_t i = 0; i < 4; i++)
    {

        // turn everything off
        digitalWrite(SCORE_LATCH_PIN, LOW);
        digitalWrite(PLAYER_LATCH_PIN, LOW);
        digitalWrite(SETS_LATCH_PIN, LOW);

        for (uint8_t i = 0; i < 4; i++)
        {
            shiftOut(SCORE_DATA_PIN, SCORE_CLK_PIN, LSBFIRST, SEGMENT_OFF);
        }

        shiftOut(PLAYER_DATA_PIN, PLAYER_CLK_PIN, LSBFIRST, SEGMENT_OFF);
        shiftOut(SETS_DATA_PIN, SETS_CLK_PIN, LSBFIRST, SEGMENT_OFF);
        shiftOut(SETS_DATA_PIN, SETS_CLK_PIN, LSBFIRST, SEGMENT_OFF);

        digitalWrite(SCORE_LATCH_PIN, HIGH);
        digitalWrite(PLAYER_LATCH_PIN, HIGH);
        digitalWrite(SETS_LATCH_PIN, HIGH);
        delay(300);

        // and now everything on
        digitalWrite(SCORE_LATCH_PIN, LOW);
        digitalWrite(PLAYER_LATCH_PIN, LOW);
        digitalWrite(SETS_LATCH_PIN, LOW);

        shiftOut(SCORE_DATA_PIN, SCORE_CLK_PIN, LSBFIRST, data.firstBigSegment);
        shiftOut(SCORE_DATA_PIN, SCORE_CLK_PIN, LSBFIRST, data.secondBigSegment);
        shiftOut(SCORE_DATA_PIN, SCORE_CLK_PIN, LSBFIRST, data.thirdBigSegment);
        shiftOut(SCORE_DATA_PIN, SCORE_CLK_PIN, LSBFIRST, data.fourthdBigSegment);
        shiftOut(PLAYER_DATA_PIN, PLAYER_CLK_PIN, LSBFIRST, data.flags);
        shiftOut(SETS_DATA_PIN, SETS_CLK_PIN, LSBFIRST, data.firstSmallSegment);
        shiftOut(SETS_DATA_PIN, SETS_CLK_PIN, LSBFIRST, data.secondSmallSegment);

        digitalWrite(SCORE_LATCH_PIN, HIGH);
        digitalWrite(PLAYER_LATCH_PIN, HIGH);
        digitalWrite(SETS_LATCH_PIN, HIGH);
        if (i < 3)
            delay(700); // wait just first two cycles, last one no need to wait
    }
    Serial.println(F("Display blink end"));
}

void displayController::blinkScore()
{
    Serial.println(F("Display score blink start"));
    // It assumes the information is already displayed
    // turn everything off and then display again for 3 times
    for (uint8_t i = 0; i < 4; i++)
    {

        // turn everything off
        digitalWrite(SCORE_LATCH_PIN, LOW);
        for (uint8_t i = 0; i < 4; i++)
        {
            shiftOut(SCORE_DATA_PIN, SCORE_CLK_PIN, LSBFIRST, SEGMENT_OFF);
        }
        digitalWrite(SCORE_LATCH_PIN, HIGH);
        delay(300);

        // and now everything on
        digitalWrite(SCORE_LATCH_PIN, LOW);
        shiftOut(SCORE_DATA_PIN, SCORE_CLK_PIN, LSBFIRST, data.firstBigSegment);
        shiftOut(SCORE_DATA_PIN, SCORE_CLK_PIN, LSBFIRST, data.secondBigSegment);
        shiftOut(SCORE_DATA_PIN, SCORE_CLK_PIN, LSBFIRST, data.thirdBigSegment);
        shiftOut(SCORE_DATA_PIN, SCORE_CLK_PIN, LSBFIRST, data.fourthdBigSegment);
        digitalWrite(SCORE_LATCH_PIN, HIGH);
        if (i < 3)
            delay(700); // wait just first two cycles, last one no need to wait
    }
    Serial.println(F("Display score blink ends"));
}
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

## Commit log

2018-09-01 Adding motherboard scheme
    [Motherboard.sch]
2018-09-01 Added other conectors for devices
    [Motherboard.sch]
2018-09-01 Added mising resistor, better PCB positioning
    [Motherboard.brd, Motherboard.sch]
2018-09-08 Added schematic and board for score controller that controls the individual LED strip. There must one board for 7 LED strips max
    [Score controller.brd, Score controller.sch]
2018-09-18 Changed transistor type for score controller, changed number of terminals to 8. Motherboard still TBD
    [Motherboard.brd, Motherboard.sch, Score controller.brd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]
2018-10-20 Finished code for blinking display + code for reseting game. Need to provide some class for logging information that applications can read it
    [constants.h, displayController.cpp, scoreController.cpp]
2019-03-11 Added setting controller class with simple imeplemntation of reading the current settings.
2019-03-13 Changed matherboard scheme and start designing PCB
    Scheme was changed to make easier PCB design. Still need to finish VCC layer on TOP layer
    [Motherboard.brd, Motherboard.sch]
2019-03-16 Finalized board for motherboard
    [Motherboard.brd, Motherboard.sch]
2019-03-16 Added capacitors for filtering
    [Motherboard.brd, Motherboard.sch]
2019-03-29 Add second environment for testing board - ArduinoUno
2019-03-29 Chnaged all switch transistor to BC-337 TO92 AMMO
    [Score controller.brd, Score controller.sch]
2019-03-29 All pins were confirmed, PCB designed
2019-03-29 Fixed code for score controller
    [main.cpp, scoreController.cpp]
2019-03-31 Added more logging fixed bug with displaying numbers above 9
    [constants.h, displayController.cpp]
2019-03-31 Added pin mode, not really sure I had to do that
2019-03-31 for ARDUINO NANO I need to switch the pins for bluetooth module!!
2019-03-31 Added polygons
    [Score controller.brd]
2019-03-31 Added polygon and make more space for screws
    [Motherboard.brd, Motherboard.sch]
2019-03-31 Changed the board to be just one layer
    [Score controller.brd]
2019-04-01 Added scheme for wiring
    [Scoreboard wire connection.sch]
2019-04-01 Updated pins to reflect PCB
2019-04-02 Uploaded smaller image of powered scoreboard
2019-04-03 Added link to LED strips and added size of the board
2019-04-03 Added images of PCB to the readme
2019-04-03 Added more space for screws
    [Score controller.brd]
2019-04-03 Made the pictures of PCB smaller
2019-04-16 Added connector labels for printing
    [Connector labels.xlsx]
2019-04-16 Added fixes during real testing
    [constants.h, displayController.cpp, main.cpp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]
2019-04-16 Fixed error with A6, A7 pin plus couple major changes
    The pin A6 & A7 cannot be used for anything digital on Nano. So removed
    Also moved the bluetooth pins and removed buttons for sets to get some free pin. Made the bluetooth module powered by 3.3V so we don't need to use voltage divider. Also made the 9V available so we can use it for powering all the score controllers
    [Motherboard.brd, Motherboard.sch]
2019-04-23 Added labels for UNO terminal
    [Connector labels.xlsx]
2019-04-26 Finished code for setting players, added reset command , minor changes
    [constants.h, main.cpp, scoreController.cpp]
2019-04-29 PCBs images and back side
2019-04-29 Re-color connectors
    [Connector labels.xlsx]
2019-04-30 Printing result of a set and match to bluetooth
2019-04-30 Correct typo in the file name, updated travis
    [settingController.cpp]
2019-05-01 Re-colored connector labels
    [Connector labels.xlsx]
2019-05-01 Fixed connection plan, added pins
    [Motherboard.brd, Scoreboard wire connection.sch]
2019-05-01 Initial structure for the wireless controller
2019-05-01 added code for all buttons
2019-05-06 Added config file plus minor changes for LED
2019-05-28 CHanged pins and removed unused buttons
2019-05-30 Added scheme for wireless buttons with self shutdown
    [Wireless button.sch]
2019-06-05 Added code for self shutdown and power button. Pins need to be verified
2019-06-05 Adjusted code for wireless communication
2019-06-13 Updated scheme and added board. Pins are not zet aligned with code
    [Wireless button.brd, Wireless button.sch]
2019-06-28 Added paper cover on the box
    [Box cover.xlsx]
2019-06-28 Synchronize pins with PCB
2019-06-28 Platform IO supporting files
    [Box cover.xlsx]
2019-06-28 Power for 433Mhz transmitter taking from 5V
    [Wireless button.brd, Wireless button.sch]
2019-07-03 Displaying minutes are not taken directly from millis. Added handling for long running games
2019-07-03 Added minute timer settings
2019-09-12 Fixed bug with settings mode. Added code for turning off sets and players
    [displayController.cpp, main.cpp, settingController.cpp]
2020-02-10 Set up a free play as the default setting. Fixed bug with minutes
    [displayController.cpp, main.cpp]
2021-02-04 BREAKING CHANGE. Changed pin, you need to re-connect
2021-02-04 Added code for turning the scoreboard to clock mode
    [Motherboard.sch]
2021-02-04 Updated schema to reflect latest changes
    The 433Mhz pin was moved to A3 and pin A4 and A5 are now used by the real time clock generator
    [Motherboard.sch]
2021-02-05 Updated wiring
    [Connector labels.xlsx, Scoreboard wire connection.sch]
2021-02-07 Update wiring scheme to match real wirring with UNO
    [Scoreboard wire connection.sch]
2021-02-07 Create Scoreboard wire connection.pdf
    Added wiring scheme
2021-02-08 Fixed bug with leadin zeros, added reset after applying a setting
    [displayController.cpp, main.cpp, scoreController.cpp]
2021-02-08 Fixed bug for leading zero for minutes
    [displayController.cpp]
